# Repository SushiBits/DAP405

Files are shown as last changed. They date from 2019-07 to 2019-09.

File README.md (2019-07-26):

# DAP405 Mini Debug Probe for ARM

An advanced USB 2.0 Hi-Speed CMSIS-DAP debug probe for ARM Cortex processors.

## Introduction

DAP405 is a CMSIS-DAP compatible USB JTAG debug adapter for ARM Cortex-A and
Cortex-M processors, based on the STM32F405RG microcontroller.

This project is an evolution of[my DAP42 project](https://github.com/SushiBits/DAP42).

## License and contact

This is open source hardware under [3-clause BSD license](LICENSE.md).

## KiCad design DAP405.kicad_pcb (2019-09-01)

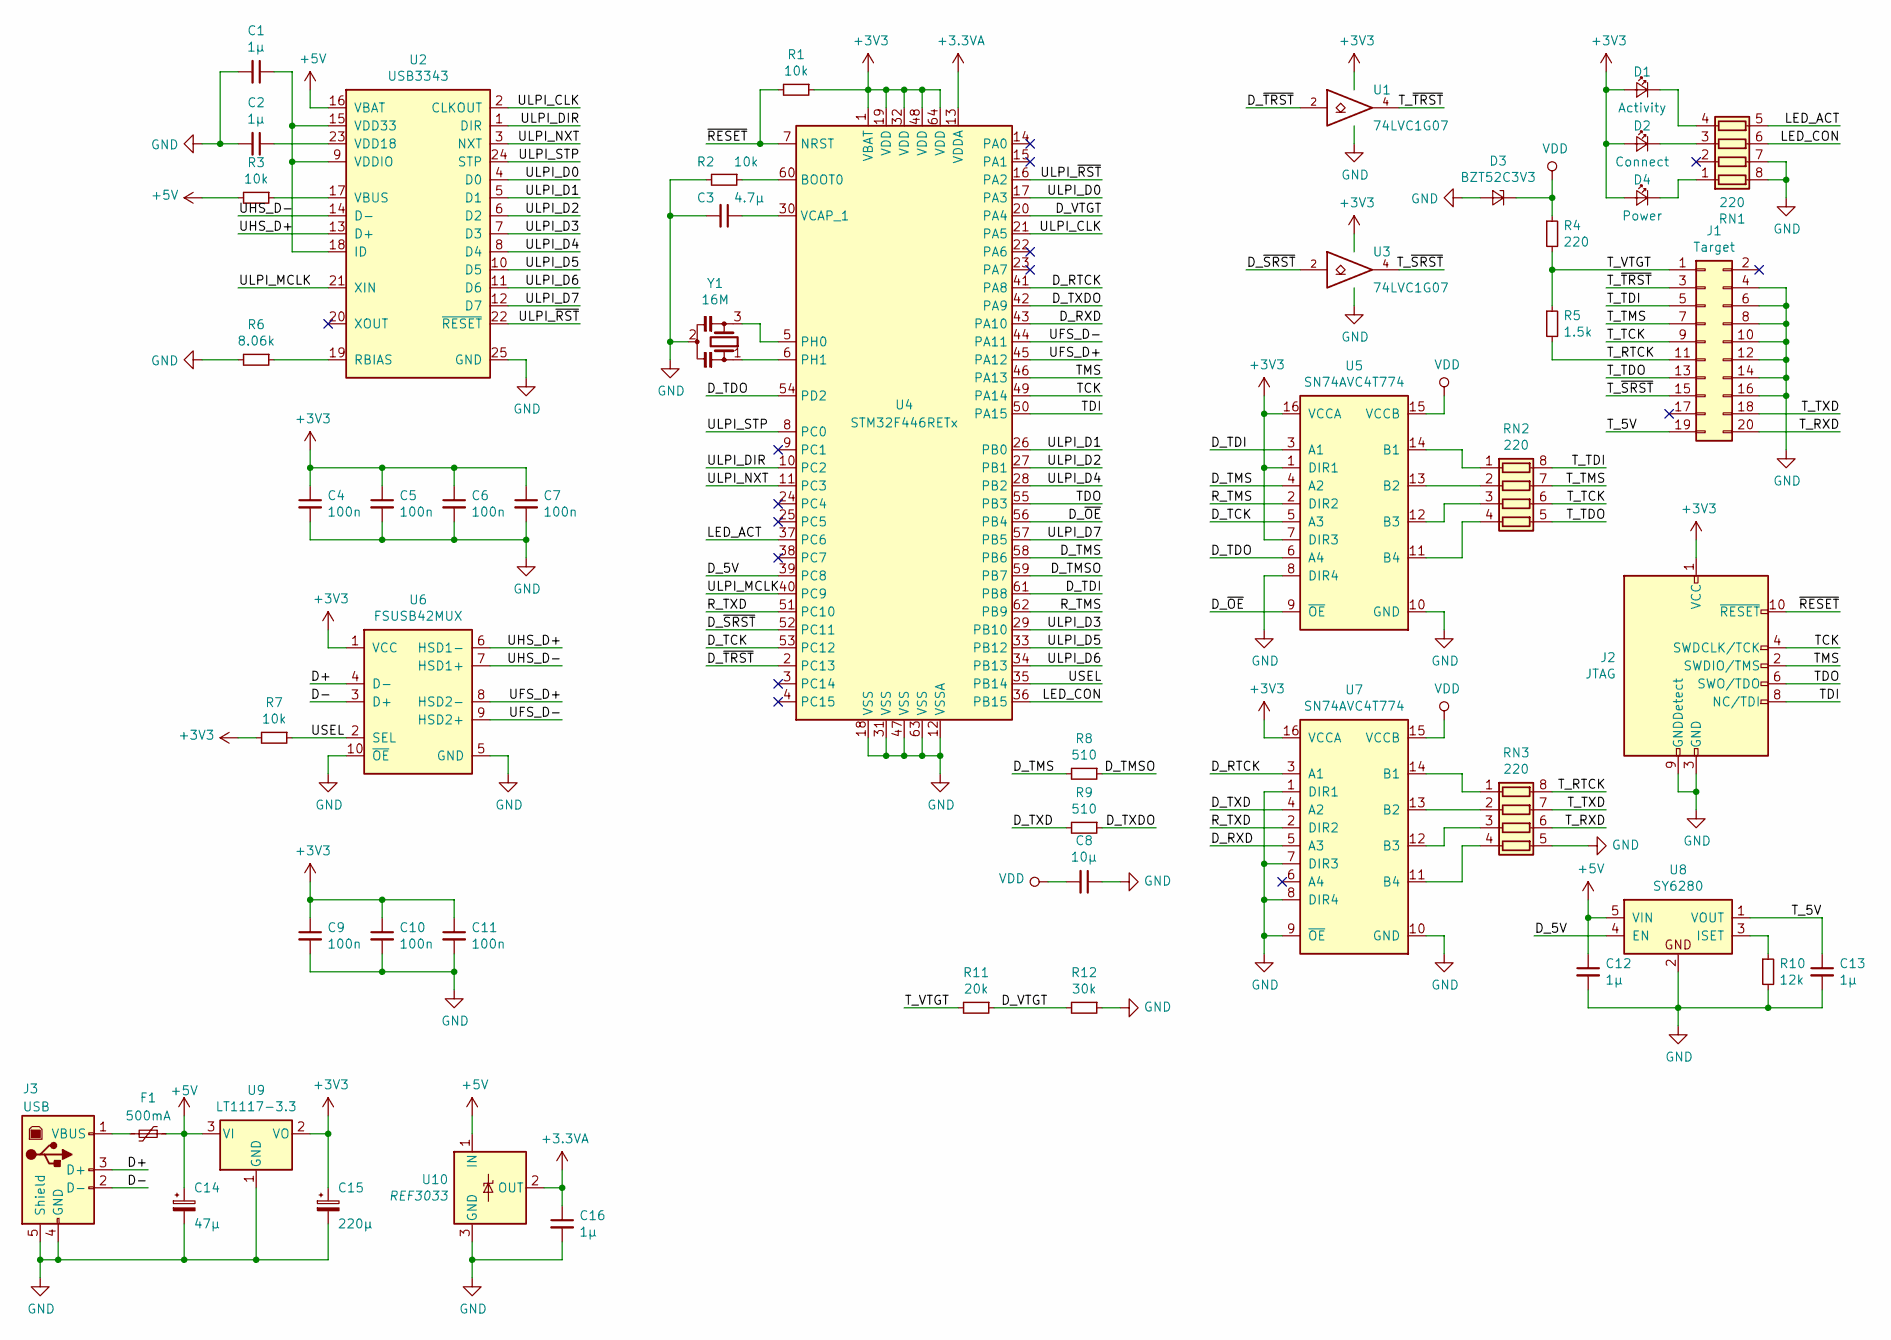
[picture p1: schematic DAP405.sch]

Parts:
C1, C2, C12, C13, C16: 1µ; C_0603_1608Metric_Pad1.05x0.95mm_HandSolder
C3: 4.7µ; C_0603_1608Metric_Pad1.05x0.95mm_HandSolder
C4, C5, C6, C7, C9, C10, C11: 100n; C_0603_1608Metric_Pad1.05x0.95mm_HandSolder
C8: 10µ; C_0805_2012Metric_Pad1.15x1.40mm_HandSolder
C14: 47µ; CP_EIA-3528-21_Kemet-B_Pad1.50x2.35mm_HandSolder
C15: 220µ; CP_EIA-3528-21_Kemet-B_Pad1.50x2.35mm_HandSolder
D1: Activity; LED_D3.0mm
D2: Connect; LED_D3.0mm
D3: BZT52C3V3; D_SOD-123
D4: Power; LED_D3.0mm
F1: 500mA; Fuse_1812_4532Metric_Pad1.30x3.40mm_HandSolder
J1: Target; IDC-Header_2x10_P2.54mm_Horizontal
J2: JTAG; PinHeader_2x05_P1.27mm_Vertical_SMD
J3: USB; USB_B_OST_USB-B1HSxx_Horizontal
R1, R2, R3, R7: 10k; R_0603_1608Metric_Pad1.05x0.95mm_HandSolder
R4: 220; R_0603_1608Metric_Pad1.05x0.95mm_HandSolder
R5: 1.5k; R_0603_1608Metric_Pad1.05x0.95mm_HandSolder
R6: 8.06k; R_0603_1608Metric_Pad1.05x0.95mm_HandSolder
R8, R9: 510; R_0603_1608Metric_Pad1.05x0.95mm_HandSolder
R10: 12k; R_0603_1608Metric_Pad1.05x0.95mm_HandSolder
R11: 20k; R_0603_1608Metric_Pad1.05x0.95mm_HandSolder
R12: 30k; R_0603_1608Metric_Pad1.05x0.95mm_HandSolder
RN1, RN2, RN3: 220; R_Array_Convex_4x0603
U1, U3: 74LVC1G07; SOT-23-5
U2: USB3343; QFN-24-1EP_4x4mm_P0.5mm_EP2.6x2.6mm
U4: STM32F446RETx; LQFP-64_10x10mm_P0.5mm
U5, U7: SN74AVC4T774; TSSOP-16_4.4x5mm_P0.65mm
U6: FSUSB42MUX; MSOP-10_3x3mm_P0.5mm
U8: SY6280; SOT-23-5
U9: LT1117-3.3; SOT-89-3
U10: REF3033; SOT-23
Y1: 16M; Resonator_SMD_muRata_CSTxExxV-3Pin_3.0x1.1mm

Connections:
+3.3VA: C16.1, U4.13 (VDDA), U10.2 (OUT)
+3V3: C4.1, C5.1, C6.1, C7.1, C9.1, C10.1, C11.1, C15.1, D1.2 (A), D2.2 (A), D4.2 (A), J2.1 (VCC), R1.1, R7.2, U1.5 (VCC), U3.5 (VCC), U4.1 (VBAT), U4.19 (VDD), U4.32 (VDD), U4.48 (VDD), U4.64 (VDD), U5.1 (DIR1), U5.7 (DIR3), U5.16 (VCCA), U6.1 (VCC), U7.16 (VCCA), U9.2 (VO)
+5V: C12.1, C14.1, F1.1, R3.2, U2.16 (VBAT), U8.5 (VIN), U9.3 (VI), U10.1 (IN)
/D+: J3.3 (D+), U6.4 (D-)
/D-: J3.2 (D-), U6.3 (D+)
/D_5V: U4.39 (PC8), U8.4 (EN)
/D_RTCK: U4.41 (PA8), U7.3 (A1)
/D_RXD: U4.43 (PA10), U7.5 (A3)
/D_TCK: U4.53 (PC12), U5.5 (A3)
/D_TDI: U4.61 (PB8), U5.3 (A1)
/D_TDO: U4.54 (PD2), U5.6 (A4)
/D_TMS: R8.2, U4.58 (PB6), U5.4 (A2)
/D_TMSO: R8.1, U4.59 (PB7)
/D_TXD: R9.2, U7.4 (A2)
/D_TXDO: R9.1, U4.42 (PA9)
/D_VTGT: R11.1, R12.2, U4.20 (PA4)
/D_~OE: U4.56 (PB4), U5.9 (~OE)
/D_~SRST: U3.2, U4.52 (PC11)
/D_~TRST: U1.2, U4.2 (PC13)
/LED_ACT: RN1.5 (R4.2), U4.37 (PC6)
/LED_CON: RN1.6 (R3.2), U4.36 (PB15)
/R_TMS: U4.62 (PB9), U5.2 (DIR2)
/R_TXD: U4.51 (PC10), U7.2 (DIR2)
/TCK: J2.4 (SWDCLK/TCK), U4.49 (PA14)
/TDI: J2.8 (NC/TDI), U4.50 (PA15)
/TDO: J2.6 (SWO/TDO), U4.55 (PB3)
/TMS: J2.2 (SWDIO/TMS), U4.46 (PA13)
/T_5V: C13.1, J1.19, U8.1 (VOUT)
/T_RTCK: J1.11, R5.2, RN3.8 (R1.2)
/T_RXD: J1.20, RN3.6 (R3.2)
/T_TCK: J1.9, RN2.6 (R3.2)
/T_TDI: J1.5, RN2.8 (R1.2)
/T_TDO: J1.13, RN2.5 (R4.2)
/T_TMS: J1.7, RN2.7 (R2.2)
/T_TXD: J1.18, RN3.7 (R2.2)
/T_VTGT: J1.1, R4.2, R5.1, R11.2
/T_~SRST: J1.15, U3.4
/T_~TRST: J1.3, U1.4
/UFS_D+: U4.45 (PA12), U6.8 (HSD2-)
/UFS_D-: U4.44 (PA11), U6.9 (HSD2+)
/UHS_D+: U2.13 (D+), U6.6 (HSD1-)
/UHS_D-: U2.14 (D-), U6.7 (HSD1+)
/ULPI_CLK: U2.2 (CLKOUT), U4.21 (PA5)
/ULPI_D0: U2.4 (D0), U4.17 (PA3)
/ULPI_D1: U2.5 (D1), U4.26 (PB0)
/ULPI_D2: U2.6 (D2), U4.27 (PB1)
/ULPI_D3: U2.7 (D3), U4.29 (PB10)
/ULPI_D4: U2.8 (D4), U4.28 (PB2)
/ULPI_D5: U2.10 (D5), U4.33 (PB12)
/ULPI_D6: U2.11 (D6), U4.34 (PB13)
/ULPI_D7: U2.12 (D7), U4.57 (PB5)
/ULPI_DIR: U2.1 (DIR), U4.10 (PC2)
/ULPI_MCLK: U2.21 (XIN), U4.40 (PC9)
/ULPI_NXT: U2.3 (NXT), U4.11 (PC3)
/ULPI_STP: U2.24 (STP), U4.8 (PC0)
/ULPI_~RST: U2.22 (~RESET), U4.16 (PA2)
/USEL: R7.1, U4.35 (PB14), U6.2 (SEL)
/~RESET: J2.10 (~RESET~), R1.2, U4.7 (NRST)
GND: C1.2, C2.2, C3.2, C4.2, C5.2, C6.2, C7.2, C8.1, C9.2, C10.2, C11.2, C12.2, C13.2, C14.2, C15.2, C16.2, D3.2 (A), J1.4, J1.6, J1.8, J1.10, J1.12, J1.14, J1.16, J2.3 (GND), J2.5 (GND), J2.9 (GNDDetect), J3.4 (GND), J3.5 (Shield), R2.2, R6.2, R10.2, R12.1, RN1.7 (R2.2), RN1.8 (R1.2), RN3.5 (R4.2), U1.3 (GND), U2.25 (GND), U3.3 (GND), U4.12 (VSSA), U4.18 (VSS), U4.31 (VSS), U4.47 (VSS), U4.63 (VSS), U5.8 (DIR4), U5.10 (GND), U6.5 (GND), U6.10 (~OE), U7.1 (DIR1), U7.7 (DIR3), U7.8 (DIR4), U7.9 (~OE), U7.10 (GND), U8.2, U9.1 (GND), U10.3 (GND), Y1.2
unnamed: C1.1, U2.9 (VDDIO), U2.15 (VDD33), U2.18 (ID)
unnamed: C2.1, U2.23 (VDD18)
unnamed: C3.1, U4.30 (VCAP_1)
unnamed: D1.1 (K), RN1.4 (R4.1)
unnamed: D2.1 (K), RN1.3 (R3.1)
unnamed: D4.1 (K), RN1.1 (R1.1)
unnamed: F1.2, J3.1 (VBUS)
unnamed: R2.1, U4.60 (BOOT0)
unnamed: R3.1, U2.17 (VBUS)
unnamed: R6.1, U2.19 (RBIAS)
unnamed: R10.1, U8.3 (ISET)
unnamed: RN2.1 (R1.1), U5.14 (B1)
unnamed: RN2.2 (R2.1), U5.13 (B2)
unnamed: RN2.3 (R3.1), U5.12 (B3)
unnamed: RN2.4 (R4.1), U5.11 (B4)
unnamed: RN3.1 (R1.1), U7.14 (B1)
unnamed: RN3.2 (R2.1), U7.13 (B2)
unnamed: RN3.3 (R3.1), U7.12 (B3)
unnamed: RN3.4 (R4.1), U7.11 (B4)
unnamed: U4.5 (PH0), Y1.3
unnamed: U4.6 (PH1), Y1.1
VDD: C8.2, D3.1 (K), R4.1, U5.15 (VCCB), U7.15 (VCCB)

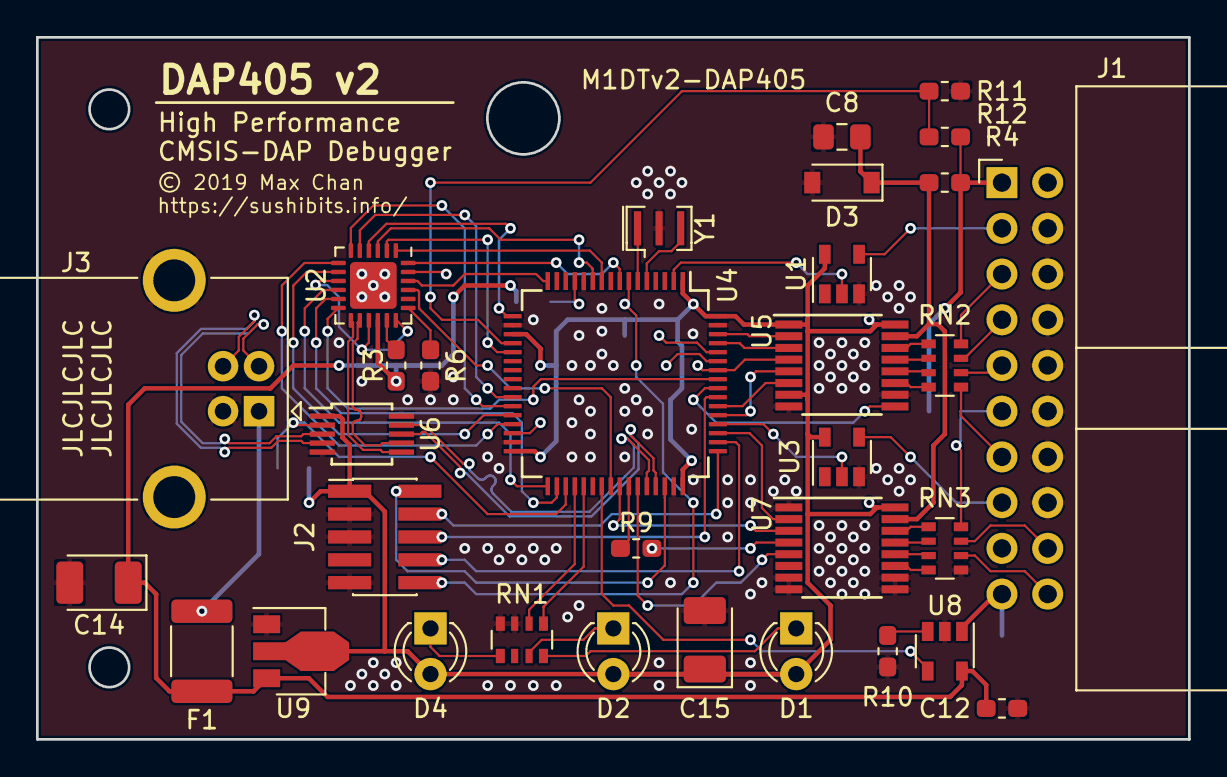
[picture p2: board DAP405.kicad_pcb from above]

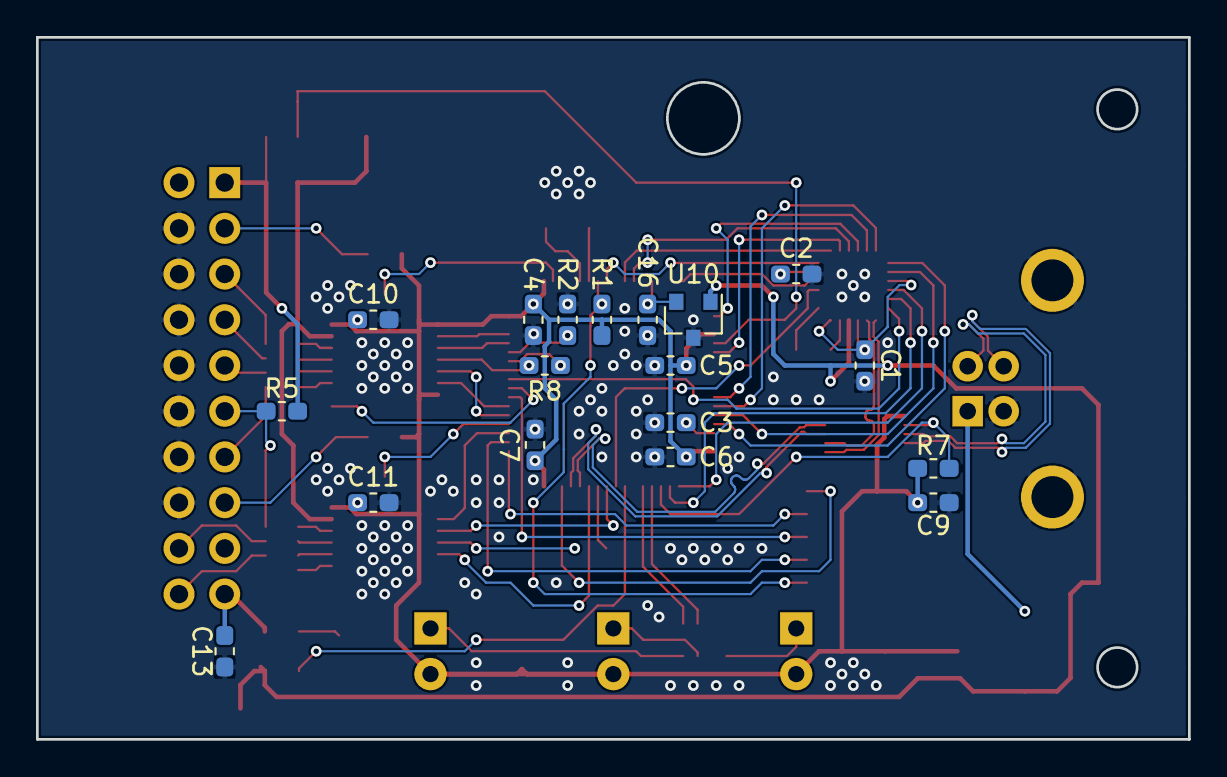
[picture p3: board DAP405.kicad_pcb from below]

Board: 2 copper layers, 64.0 x 39.0 mm, 50 parts (18 on the bottom side), 81 nets.

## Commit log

2019-07-26 Code dump
    [DAP405.kicad_pcb, DAP405.sch]
2019-07-26 Fixing the ULPI interface.
    [DAP405.kicad_pcb, DAP405.sch]
2019-09-01 STM32F446 version
    [DAP405.kicad_pcb, DAP405.sch]

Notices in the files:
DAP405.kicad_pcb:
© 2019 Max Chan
